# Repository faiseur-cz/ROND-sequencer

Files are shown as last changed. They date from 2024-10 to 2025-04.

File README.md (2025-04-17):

WARNING : It has been reported on modwiggler that this circuit is NOT OK!!! So please, check the forum. There were some solutions given. 
Right now i will not take the time needed to redo everything, because it would need some global redesign, and this project is not a priority for me.
Feel free to do it and write me directly or on the forum, it would be great!

Original description :
I finished the design and built a couple of them, all works as it should. So you can use the gerbers to make your own version.

There is a thread on modwiggler if you have any question :
https://modwiggler.com/forum/viewtopic.php?t=284588

ROND is an 8 step analog sequencer, kind of augmented (and circular!) baby8

- Pattern length rotary switch to set the number of steps in your sequence
- You can choose between two levels of CV (5v/2.5v), if you need more or less precision in the tuning of each step.
- Gates on/off for each step, on the right of the module.
- Run/Tune switch and Next Step push-button to facilitate tuning

CALIBRATION PROCEDURE :
- set the Run/Tune switch in TUNE position
- make sure the selected gate switch is ON (high position) and the corresponding pot is fully clockwise (maximum CV)
- monitor the CV output voltage and turn the trimpots until you reach precisely 5V (with the switch in 5V position) and 2.5V (with the switch in 2.5V position)
- DONE!

ROND - panel
ROND - pcb front
ROND - pcb back

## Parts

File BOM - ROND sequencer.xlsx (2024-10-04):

ROND SEQUENCER – BOM
Designator | Footprint | Qty | Designation | +++
DIODES/LED
LED6,LED5,LED1,LED2,LED3,LED8,LED4,LED7 | LED_D3.0mm | 8 | LED
D28,D14,D21,D27,D13,D4,D3,D22,D23,D5, D15,D6,D7,D20,D29,D8,D11,D24,D19,D30,D16 | D_DO-35_SOD27_P7.62mm_Horizontal | 21 | 1N4148
JACKS
RESET_IN1,CLOCK_IN1,GATE_OUT1, CV_OUT1,CLOCK_OUT1 | Jack_3.5mm | 5 | Jacks
SWITCHES
SW10 | SW_2MS1T1B1M2QES | 1 | 5v/2.5v | SMTS-102-A2
SW1,SW7,SW4,SW9,SW2,SW6,SW5,SW8 | SW_2MS1T1B1M2QES | 8 | SMTS-201 | SMTS-102-A2
SW11 | SW_2MS1T1B1M2QES | 1 | run/tune | SMTS-102-A2
S1 | SR1712F010820F0AN9N027 | 1 | Rotary Switch 1P8T
SW3 | D6F90F1LFS | 1 | next step Push Switch
TRANSISTORS
Q4,Q7,Q3,Q2,Q1,Q8,Q6,Q5 | TO-92_Inline_Wide | 8 | 2N3904
CAPACITORS
C5,C4 | CP_Radial_D5.0mm_P2.00mm | 2 | 47uf | POLARIZED
C3 | C_Rect_L7.2mm_W3.5mm_P5.00mm | 1 | 1nf | FILM
C2 | C_Disc_D5.0mm_W2.5mm_P5.00mm | 1 | 220nf | CERAMIC
C1 | C_Rect_L7.2mm_W3.5mm_P5.00mm | 1 | 1uf | FILM
C7,C9,C8,C6 | C_Disc_D3.0mm_W2.0mm_P2.50mm | 4 | 100nf | CERAMIC
RESISTORS
R12,R5,R10,R2,R3,R13,R16,R20,R6,R1, R7,R15,R11,R28,R27,R25 | R_Axial_DIN0207_L6.3mm_D2.5mm_P7.62mm_Horizontal | 16 | 100k
R24 | R_Axial_DIN0207_L6.3mm_D2.5mm_P7.62mm_Horizontal | 1 | 6.8k
R29,R36,R34,R33,R30,R35,R32,R31,R18,R26,R23 | R_Axial_DIN0207_L6.3mm_D2.5mm_P7.62mm_Horizontal | 11 | 1k
R9,R8 | R_Axial_DIN0207_L6.3mm_D2.5mm_P7.62mm_Horizontal | 2 | 10k
R19 | R_Axial_DIN0207_L6.3mm_D2.5mm_P7.62mm_Horizontal | 1 | 68k
R4 | R_Axial_DIN0207_L6.3mm_D2.5mm_P7.62mm_Horizontal | 1 | 33k
R17 | R_Axial_DIN0207_L6.3mm_D2.5mm_P7.62mm_Horizontal | 1 | 51k
R22 | R_Axial_DIN0207_L6.3mm_D2.5mm_P7.62mm_Horizontal | 1 | 18k
R37 | R_Axial_DIN0207_L6.3mm_D2.5mm_P7.62mm_Horizontal | 1 | 100
POTENTIOMETERS
RV8,RV2,RV6,RV5,RV4,RV7,RV3,RV1 | Potentiometer_Alpha_RD901F-40-00D_Single_Vertical | 8 | B100k
RV9 | Potentiometer_Alpha_RD901F-40-00D_Single_Vertical | 1 | B250k-1M
TRIMMERS
R14 | Bourns_3296W_Vertical | 1 | 5k
R21 | Bourns_3296W_Vertical | 1 | 2k
MISC
J1 | IDC-Header_2x05_P2.54mm_Vertical | 1 | POWER
U1 | DIP-8_W7.62mm_Socket | 1 | TL072
U3 | DIP-14_W7.62mm_Socket | 1 | TL074
U4 | DIP-16_W7.62mm_Socket | 1 | 4017

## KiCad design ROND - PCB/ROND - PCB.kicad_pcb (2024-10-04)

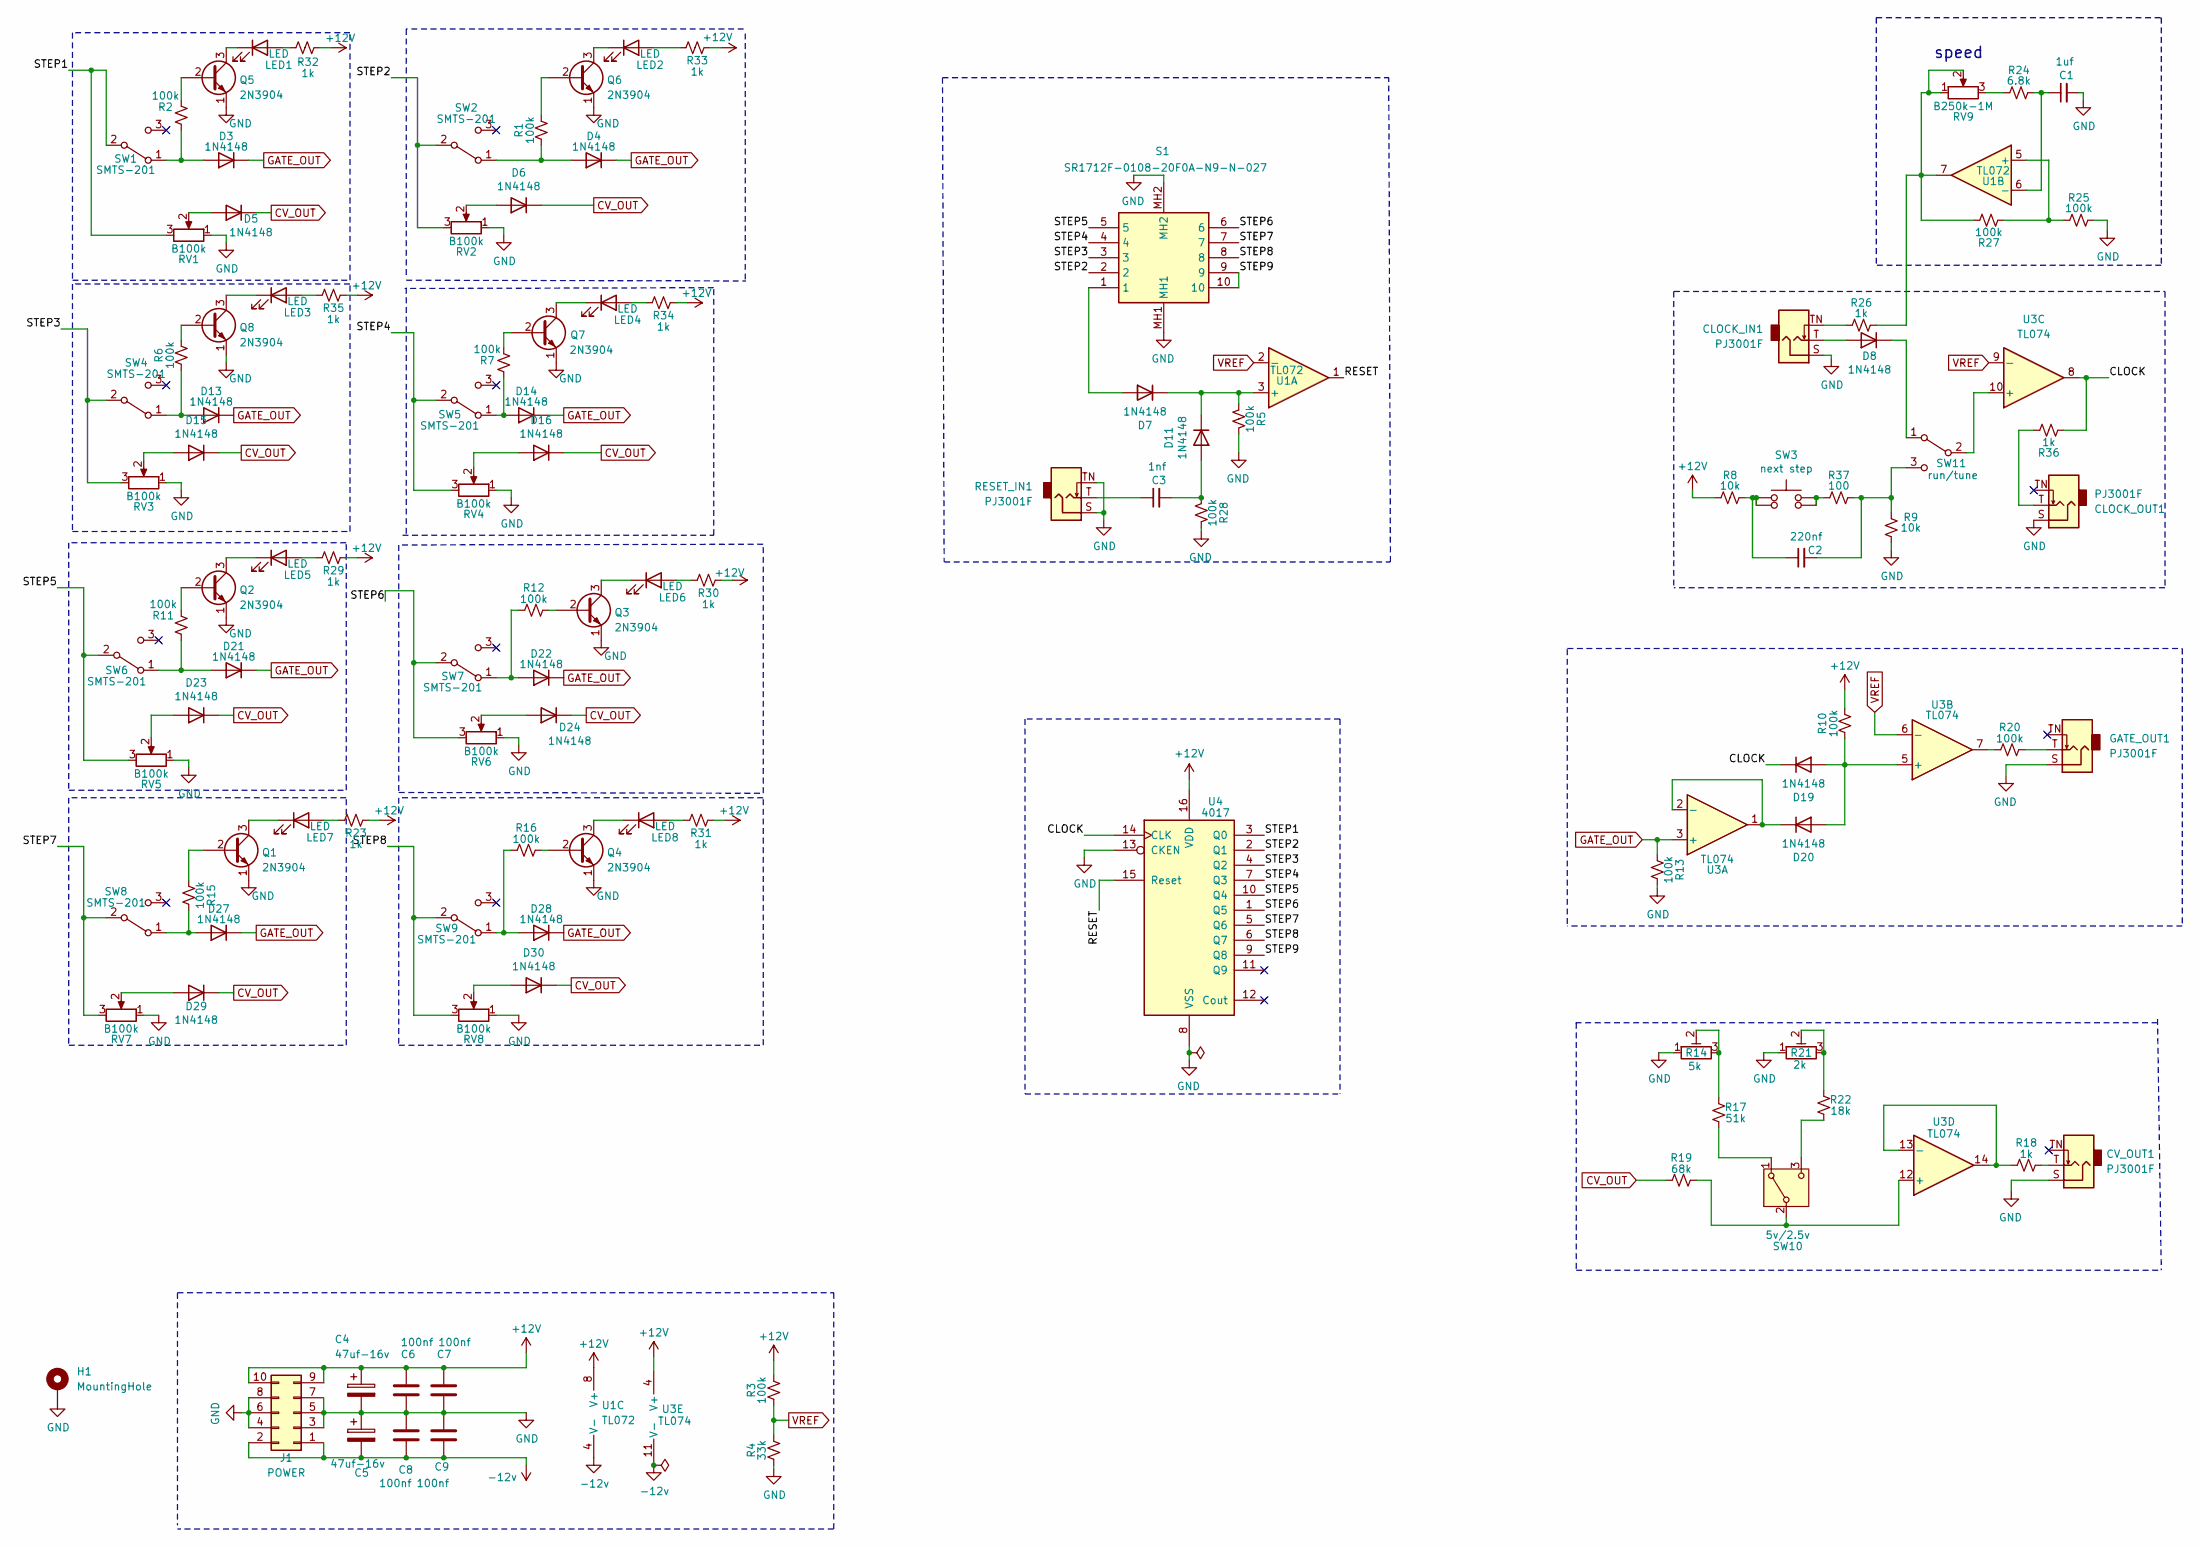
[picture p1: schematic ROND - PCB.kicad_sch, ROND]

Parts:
C1: 1uf; C_Rect_L7.2mm_W3.5mm_P5.00mm_FKS2_FKP2_MKS2_MKP2
C2: 220nf; C_Disc_D5.0mm_W2.5mm_P5.00mm
C3: 1nf; C_Rect_L7.2mm_W3.5mm_P5.00mm_FKS2_FKP2_MKS2_MKP2
C4, C5: 47uf-16v; CP_Radial_D5.0mm_P2.00mm
C6, C7, C8, C9: 100nf; C_Disc_D3.0mm_W2.0mm_P2.50mm
CLOCK_IN1: PJ3001F; Jack_3.5mm_QingPu_WQP-PJ398SM_Vertical_CircularHoles
CLOCK_OUT1: PJ3001F; Jack_3.5mm_QingPu_WQP-PJ398SM_Vertical_CircularHoles
CV_OUT1: PJ3001F; Jack_3.5mm_QingPu_WQP-PJ398SM_Vertical_CircularHoles
D3, D4, D5, D6, D7, D8, D11, D13, D14, D15, D16, D19, D20, D21, D22, D23, D24, D27, D28, D29, D30: 1N4148; D_DO-35_SOD27_P7.62mm_Horizontal
GATE_OUT1: PJ3001F; Jack_3.5mm_QingPu_WQP-PJ398SM_Vertical_CircularHoles
H1: MountingHole; MountingHole_3.2mm_M3_Pad_Via
J1: POWER; IDC-Header_2x05_P2.54mm_Vertical
LED1, LED2, LED3, LED4, LED5, LED6, LED7, LED8: LED; LED_D3.0mm
Q1, Q2, Q3, Q4, Q5, Q6, Q7, Q8: 2N3904; TO-92_Inline_Wide
R1, R2, R3, R5, R6, R7, R10, R11, R12, R13, R15, R16, R20, R25, R27, R28: 100k; R_Axial_DIN0207_L6.3mm_D2.5mm_P7.62mm_Horizontal
R4: 33k; R_Axial_DIN0207_L6.3mm_D2.5mm_P7.62mm_Horizontal
R8, R9: 10k; R_Axial_DIN0207_L6.3mm_D2.5mm_P7.62mm_Horizontal
R14: 5k; Potentiometer_Bourns_3296W_Vertical
R17: 51k; R_Axial_DIN0207_L6.3mm_D2.5mm_P7.62mm_Horizontal
R18, R23, R26, R29, R30, R31, R32, R33, R34, R35, R36: 1k; R_Axial_DIN0207_L6.3mm_D2.5mm_P7.62mm_Horizontal
R19: 68k; R_Axial_DIN0207_L6.3mm_D2.5mm_P7.62mm_Horizontal
R21: 2k; Potentiometer_Bourns_3296W_Vertical
R22: 18k; R_Axial_DIN0207_L6.3mm_D2.5mm_P7.62mm_Horizontal
R24: 6.8k; R_Axial_DIN0207_L6.3mm_D2.5mm_P7.62mm_Horizontal
R37: 100; R_Axial_DIN0207_L6.3mm_D2.5mm_P7.62mm_Horizontal
RESET_IN1: PJ3001F; Jack_3.5mm_QingPu_WQP-PJ398SM_Vertical_CircularHoles
RV1, RV2, RV3, RV4, RV5, RV6, RV7, RV8: B100k; Potentiometer_Alpha_RD901F-40-00D_Single_Vertical
RV9: B250k-1M; Potentiometer_Alpha_RD901F-40-00D_Single_Vertical
S1: SR1712F-0108-20F0A-N9-N-027; SR1712F010820F0AN9N027; Mouser Part Number 105-SR1712F-18NS
SW1, SW2, SW4, SW5, SW6, SW7, SW8, SW9: SMTS-201; SW_2MS1T1B1M2QES
SW3: next step; D6F90F1LFS
SW10: 5v/2.5v; SW_2MS1T1B1M2QES
SW11: run/tune; SW_2MS1T1B1M2QES
U1: TL072; DIP-8_W7.62mm_Socket
U3: TL074; DIP-14_W7.62mm_Socket
U4: 4017; DIP-16_W7.62mm_Socket

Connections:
+12V: C4.1, C6.1, C7.1, J1.9, J1.10, R3.1, R8.2, R10.1, R23.1, R29.1, R30.1, R31.1, R32.1, R33.1, R34.1, R35.1, U1.8 (V+), U3.4 (V+), U4.16 (VDD)
-12v: C5.2, C8.1, C9.1, J1.1, J1.2, U1.4 (V-), U3.11 (V-)
/CLOCK: D19.1 (K), R36.2, U3.8, U4.14 (CLK)
/RESET: U1.1, U4.15 (Reset)
/STEP1: RV1.3, SW1.2 (B), U4.3 (Q0)
/STEP2: RV2.3, S1.2, SW2.2 (B), U4.2 (Q1)
/STEP3: RV3.3, S1.3, SW4.2 (B), U4.4 (Q2)
/STEP4: RV4.3, S1.4, SW5.2 (B), U4.7 (Q3)
/STEP5: RV5.3, S1.5, SW6.2 (B), U4.10 (Q4)
/STEP6: RV6.3, S1.6, SW7.2 (B), U4.1 (Q5)
/STEP7: RV7.3, S1.7, SW8.2 (B), U4.5 (Q6)
/STEP8: RV8.3, S1.8, SW9.2 (B), U4.6 (Q7)
/STEP9: S1.9, S1.10, U4.9 (Q8)
CV_OUT: D5.1 (K), D6.1 (K), D15.1 (K), D16.1 (K), D23.1 (K), D24.1 (K), D29.1 (K), D30.1 (K), R19.2
GATE_OUT: D3.1 (K), D4.1 (K), D13.1 (K), D14.1 (K), D21.1 (K), D22.1 (K), D27.1 (K), D28.1 (K), R13.2, U3.3 (+)
GND: C1.2, C4.2, C5.1, C6.2, C7.2, C8.2, C9.2, CLOCK_IN1.S, CLOCK_OUT1.S, CV_OUT1.S, GATE_OUT1.S, H1.1, J1.3, J1.4, J1.5, J1.6, J1.7, J1.8, Q1.1 (E), Q2.1 (E), Q3.1 (E), Q4.1 (E), Q5.1 (E), Q6.1 (E), Q7.1 (E), Q8.1 (E), R4.2, R5.2, R9.1, R13.1, R14.1, R21.1, R25.1, R28.2, RESET_IN1.S, RESET_IN1.TN, RV1.1, RV2.1, RV3.1, RV4.1, RV5.1, RV6.1, RV7.1, RV8.1, S1.MH1, S1.MH2, U4.8 (VSS), U4.13 (CKEN)
unnamed: C2.1, R8.1, SW3.1, SW3.2
unnamed: C3.1, RESET_IN1.T
unnamed: CLOCK_IN1.TN, R26.2
unnamed: CLOCK_OUT1.T, R36.1
unnamed: CV_OUT1.T, R18.1
unnamed: D3.2 (A), R2.2, SW1.1 (A)
unnamed: D4.2 (A), R1.2, SW2.1 (A)
unnamed: D5.2 (A), RV1.2
unnamed: D6.2 (A), RV2.2
unnamed: D7.2 (A), S1.1
unnamed: CLOCK_IN1.T, D8.2 (A)
unnamed: D8.1 (K), SW11.1 (A)
unnamed: C3.2, D11.2 (A), R28.1
unnamed: D7.1 (K), D11.1 (K), R5.1, U1.3 (+)
unnamed: D13.2 (A), R6.2, SW4.1 (A)
unnamed: D14.2 (A), R7.2, SW5.1 (A)
unnamed: D15.2 (A), RV3.2
unnamed: D16.2 (A), RV4.2
unnamed: D19.2 (A), D20.2 (A), R10.2, U3.5 (+)
unnamed: D20.1 (K), U3.1, U3.2 (-)
unnamed: D21.2 (A), R11.2, SW6.1 (A)
unnamed: D22.2 (A), R12.2, SW7.1 (A)
unnamed: D23.2 (A), RV5.2
unnamed: D24.2 (A), RV6.2
unnamed: D27.2 (A), R15.1, SW8.1 (A)
unnamed: D28.2 (A), R16.2, SW9.1 (A)
unnamed: D29.2 (A), RV7.2
unnamed: D30.2 (A), RV8.2
unnamed: GATE_OUT1.T, R20.1
unnamed: LED1.2 (A), R32.2
unnamed: LED1.1 (K), Q5.3 (C)
unnamed: LED2.2 (A), R33.2
unnamed: LED2.1 (K), Q6.3 (C)
unnamed: LED3.2 (A), R35.2
unnamed: LED3.1 (K), Q8.3 (C)
unnamed: LED4.2 (A), R34.2
unnamed: LED4.1 (K), Q7.3 (C)
unnamed: LED5.2 (A), R29.2
unnamed: LED5.1 (K), Q2.3 (C)
unnamed: LED6.2 (A), R30.2
unnamed: LED6.1 (K), Q3.3 (C)
unnamed: LED7.2 (A), R23.2
unnamed: LED7.1 (K), Q1.3 (C)
unnamed: LED8.2 (A), R31.2
unnamed: LED8.1 (K), Q4.3 (C)
unnamed: Q1.2 (B), R15.2
unnamed: Q2.2 (B), R11.1
unnamed: Q3.2 (B), R12.1
unnamed: Q4.2 (B), R16.1
unnamed: Q5.2 (B), R2.1
unnamed: Q6.2 (B), R1.1
unnamed: Q7.2 (B), R7.1
unnamed: Q8.2 (B), R6.1
unnamed: R14.2, R14.3, R17.2
unnamed: R20.2, U3.7
unnamed: R21.2, R21.3, R22.2
unnamed: R24.2, RV9.3
unnamed: R26.1, R27.1, RV9.1, RV9.2, U1.7
unnamed: R37.2, SW3.3, SW3.4
unnamed: R17.1, SW10.1 (A)
unnamed: R19.1, SW10.2 (B), U3.12 (+)
unnamed: R22.1, SW10.3 (C)
unnamed: SW11.2 (B), U3.10 (+)
unnamed: C2.2, R9.2, R37.1, SW11.3 (C)
unnamed: R25.2, R27.2, U1.5 (+)
unnamed: C1.1, R24.1, U1.6 (-)
unnamed: R18.2, U3.13 (-), U3.14
VREF: R3.2, R4.1, U1.2 (-), U3.6 (-), U3.9 (-)

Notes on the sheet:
speed

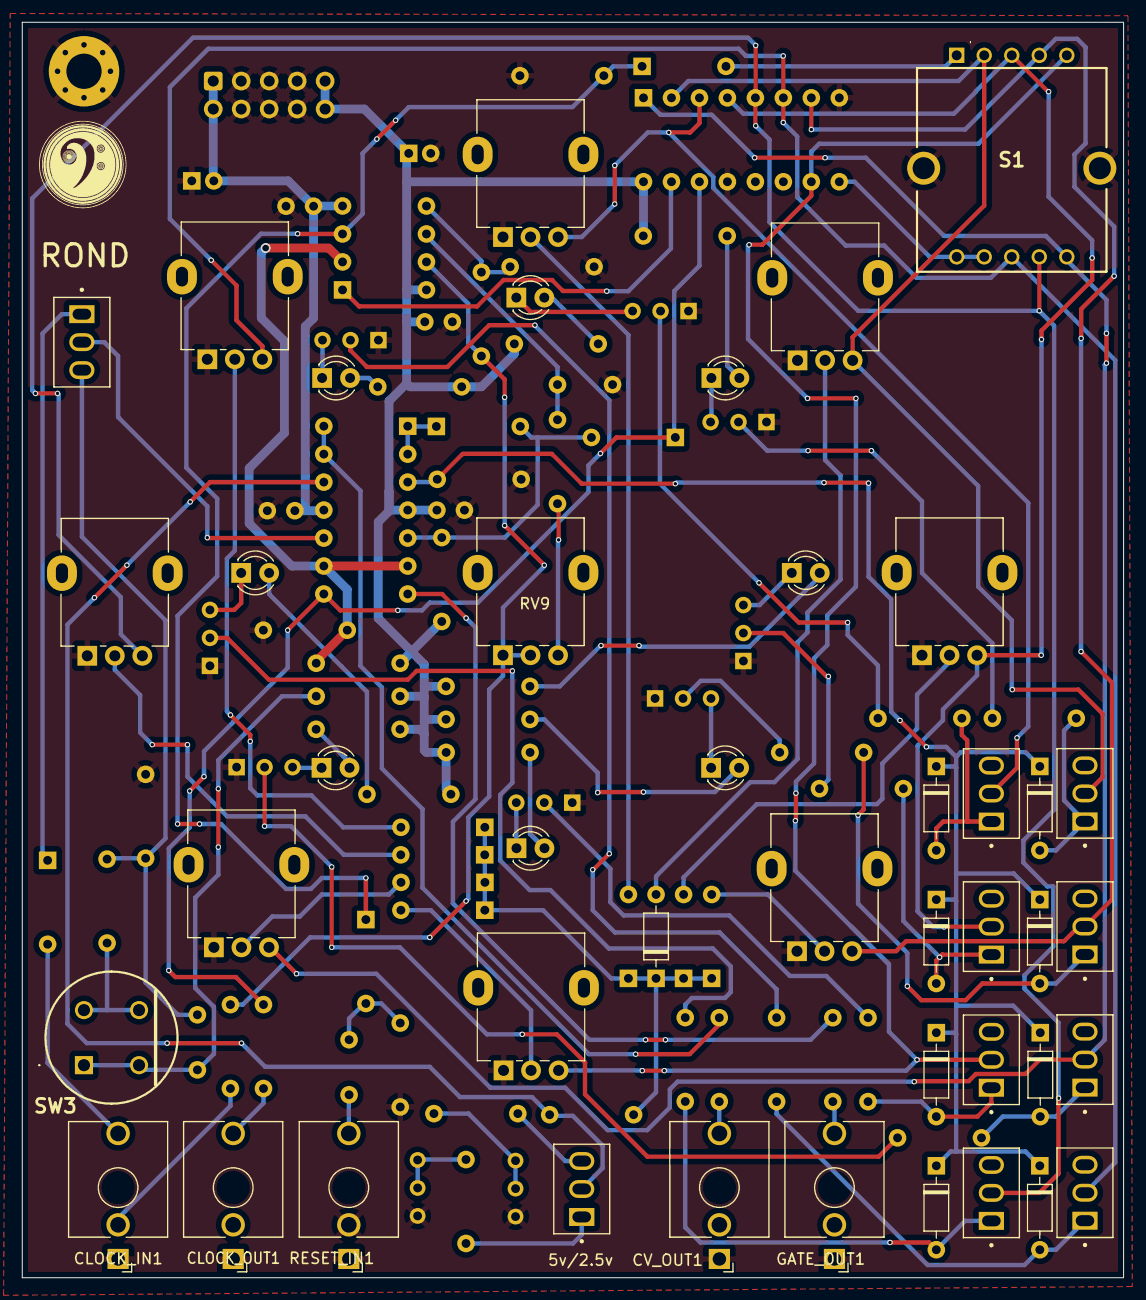
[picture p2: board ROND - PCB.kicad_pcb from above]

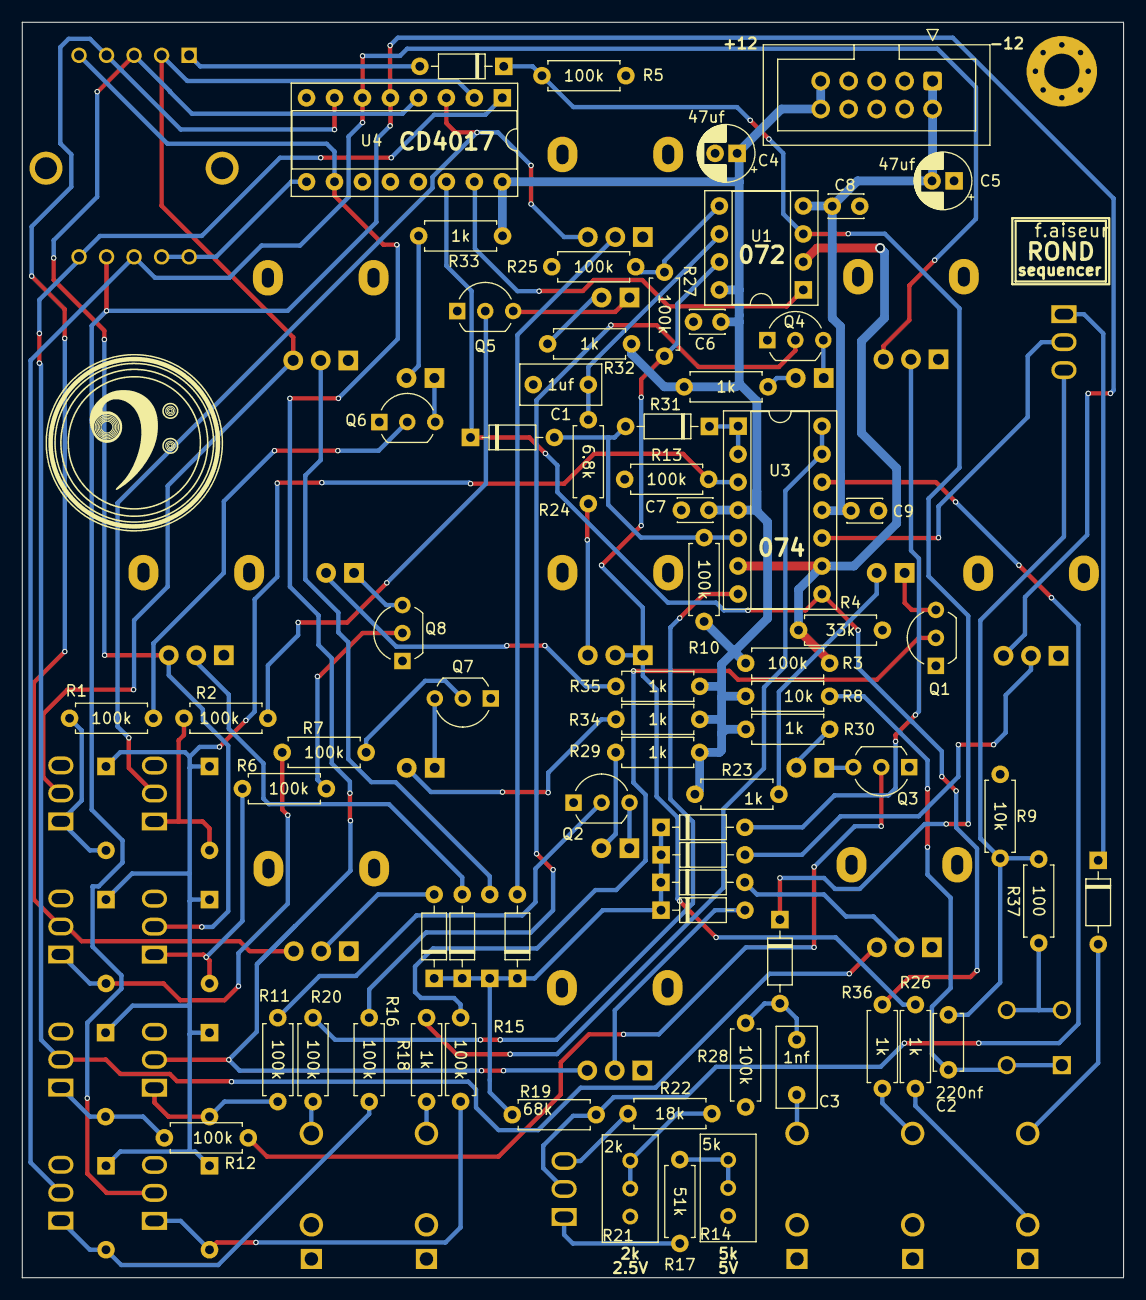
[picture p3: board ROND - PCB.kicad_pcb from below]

Board: 2 copper layers, 100.0 x 114.0 mm, 114 parts (70 on the bottom side), 84 nets.
